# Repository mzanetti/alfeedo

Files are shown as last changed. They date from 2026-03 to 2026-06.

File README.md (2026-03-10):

# Alfeedo

A fully featured, smart home integrated cat feeder. 

This repository contains the firmware for the 3D printed cat feeder Alfeedo.

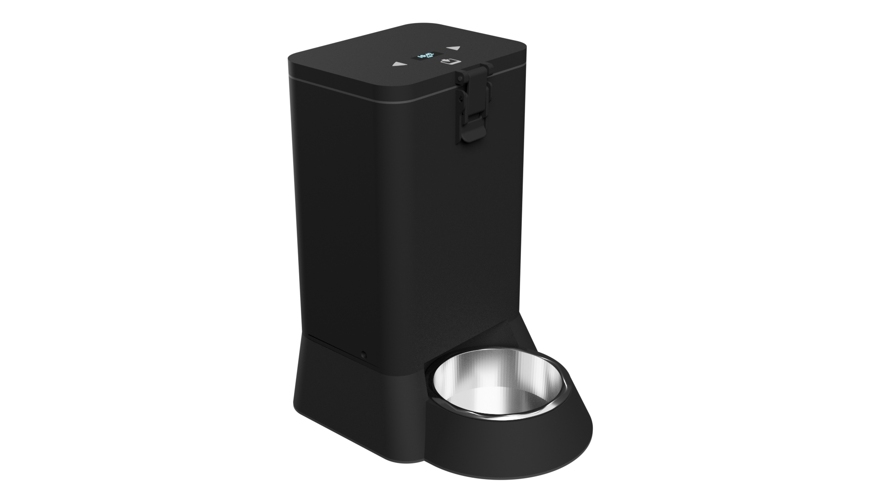
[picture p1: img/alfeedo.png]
Alfeedo


## Features

* Controls a TMC2209 stepper motor to dispense food (including jam detection and recovery)
* Supports operation and setup using a 128x32 display and Buttons
* Built-in web interface
* REST API

| Main view | Timer settings | Logs | Settings |
| :--- | :--- | :--- | :--- |
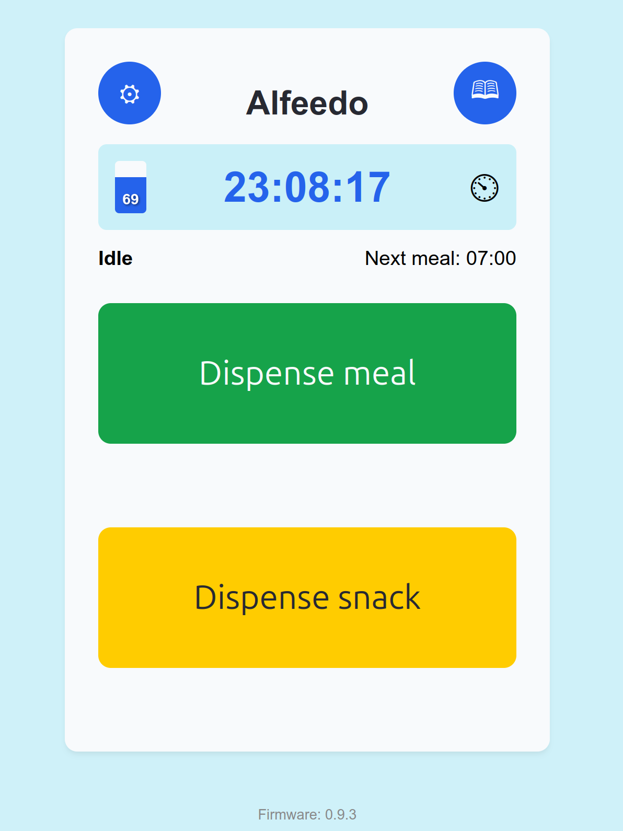
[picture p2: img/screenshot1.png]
Main
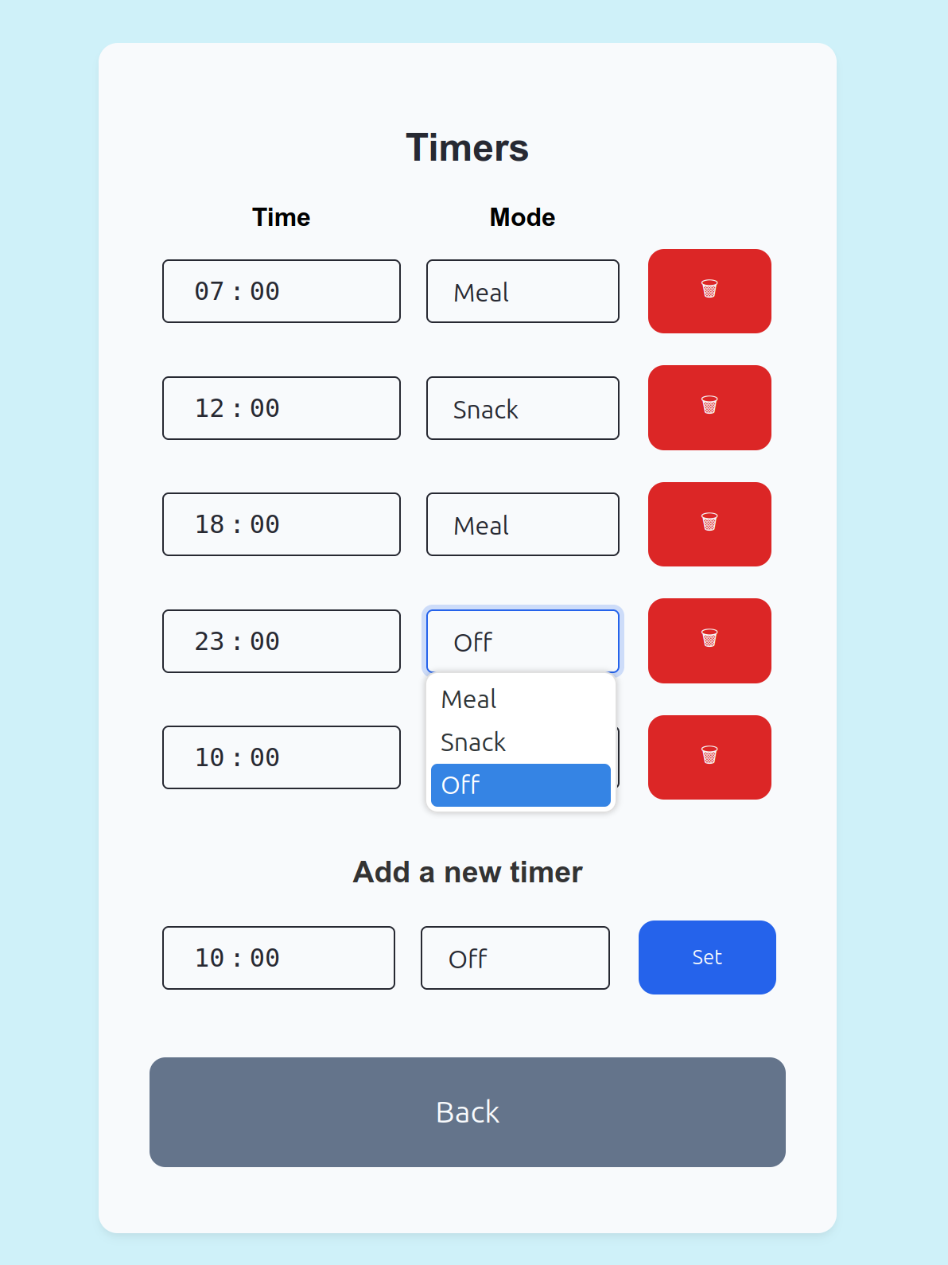
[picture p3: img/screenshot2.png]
Timers
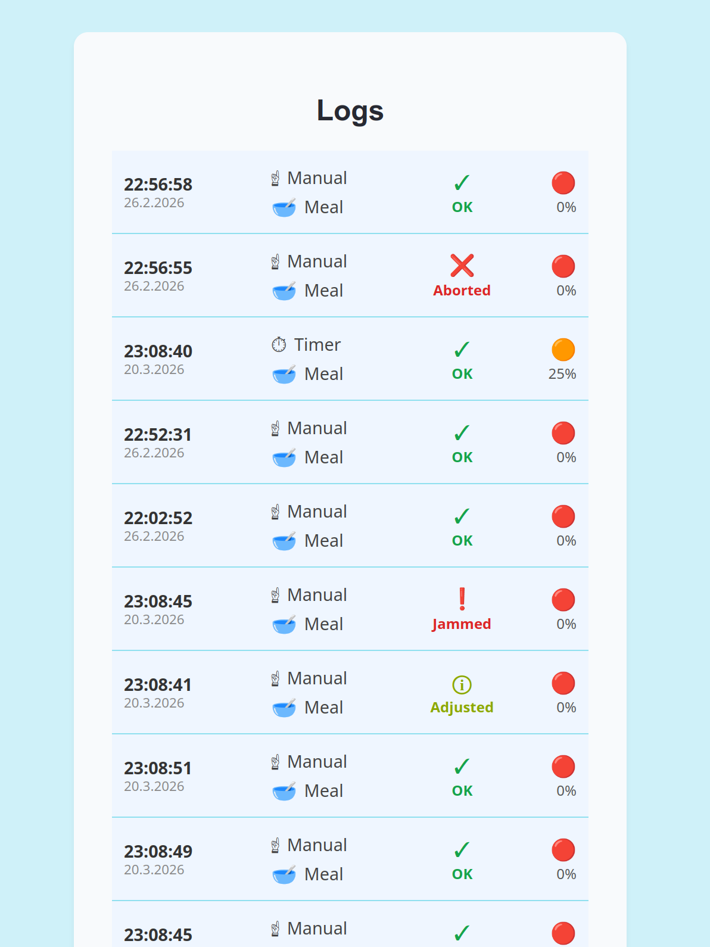
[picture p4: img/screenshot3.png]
Logs
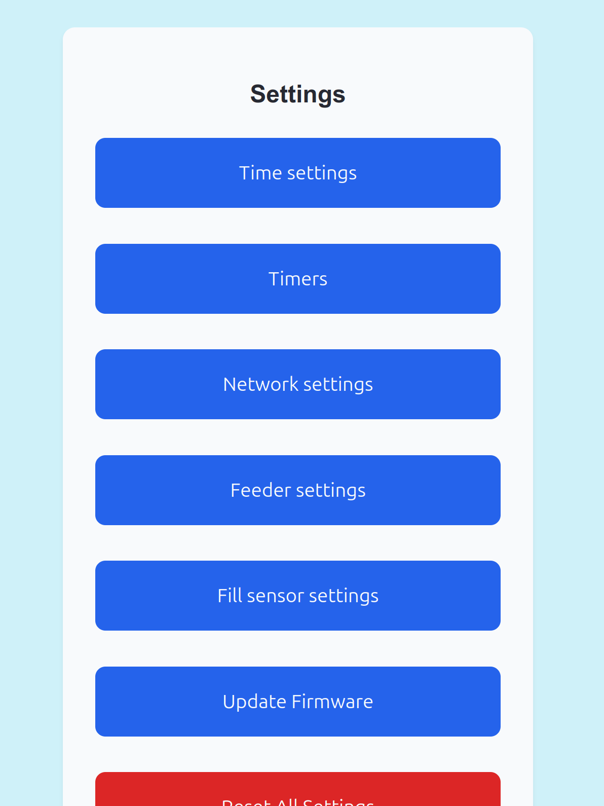
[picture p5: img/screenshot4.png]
Settings
|  |  |  |  |

## How to build

3D print model files along with a bill of materials are available on Makerworld. 

[Makerworld - Alfeedo](https://makerworld.com/en/models/2506745-alfeedo-smart-cat-feeder)

Follow print and assembly instructions provided with the model files.

Electronics wiring can be simplified by ordering the Alfeedo PCB using the provided Gerber files in [pcb/](https://github.com/mzanetti/alfeedo/tree/main/pcb).

Flash the device using the [web flasher](https://mzanetti.github.io/alfeedo/main/flasher/).

Note that the provided firmware assumes wiring to look like on the Alfeedo PCB. If instead you prefer using a different setup, you'll have to build the firmware yourself and adjust the pins in hwsettings.h.

## Building

This project is based on [platformio](https://platformio.org/).

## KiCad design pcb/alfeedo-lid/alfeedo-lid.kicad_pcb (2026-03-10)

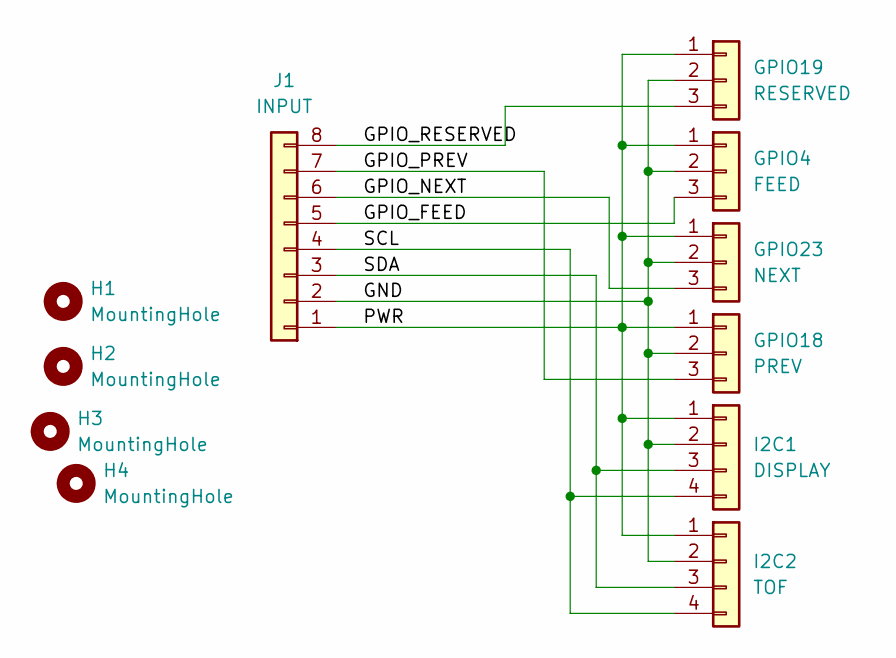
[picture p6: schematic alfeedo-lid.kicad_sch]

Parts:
GPIO4: FEED; JST_PH_S3B-PH-K_1x03_P2.00mm_Horizontal
GPIO18: PREV; JST_PH_S3B-PH-K_1x03_P2.00mm_Horizontal
GPIO19: RESERVED; JST_PH_S3B-PH-K_1x03_P2.00mm_Horizontal
GPIO23: NEXT; JST_PH_S3B-PH-K_1x03_P2.00mm_Horizontal
H1, H2, H3, H4: MountingHole; MountingHole_2.2mm_M2
I2C1: DISPLAY; JST_PH_S4B-PH-K_1x04_P2.00mm_Horizontal
I2C2: TOF; JST_PH_S4B-PH-K_1x04_P2.00mm_Horizontal
J1: INPUT; JST_PH_S8B-PH-K_1x08_P2.00mm_Horizontal

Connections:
/GND: GPIO4.2, GPIO18.2, GPIO19.2, GPIO23.2, I2C1.2, I2C2.2, J1.2
/GPIO_FEED: GPIO4.3, J1.5
/GPIO_NEXT: GPIO23.3, J1.6
/GPIO_PREV: GPIO18.3, J1.7
/GPIO_RESERVED: GPIO19.3, J1.8
/PWR: GPIO4.1, GPIO18.1, GPIO19.1, GPIO23.1, I2C1.1, I2C2.1, J1.1
/SCL: I2C1.4, I2C2.4, J1.4
/SDA: I2C1.3, I2C2.3, J1.3

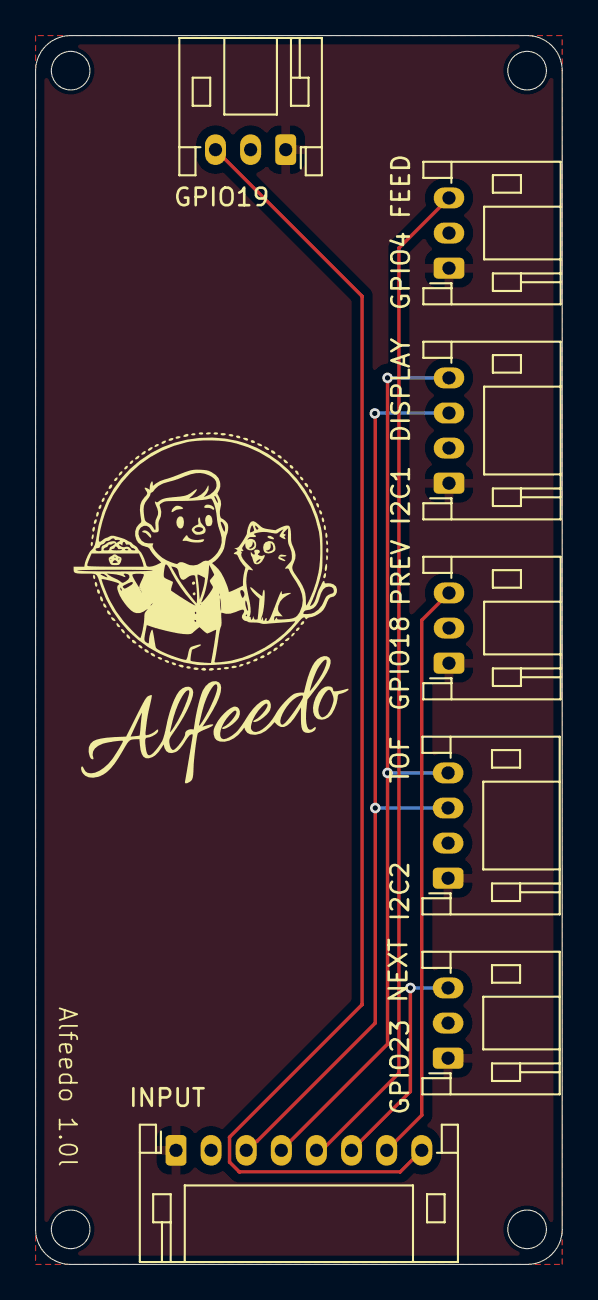
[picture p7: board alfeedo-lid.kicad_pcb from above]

Board: 2 copper layers, 30.0 x 70.0 mm, 11 parts (0 on the bottom side), 8 nets.

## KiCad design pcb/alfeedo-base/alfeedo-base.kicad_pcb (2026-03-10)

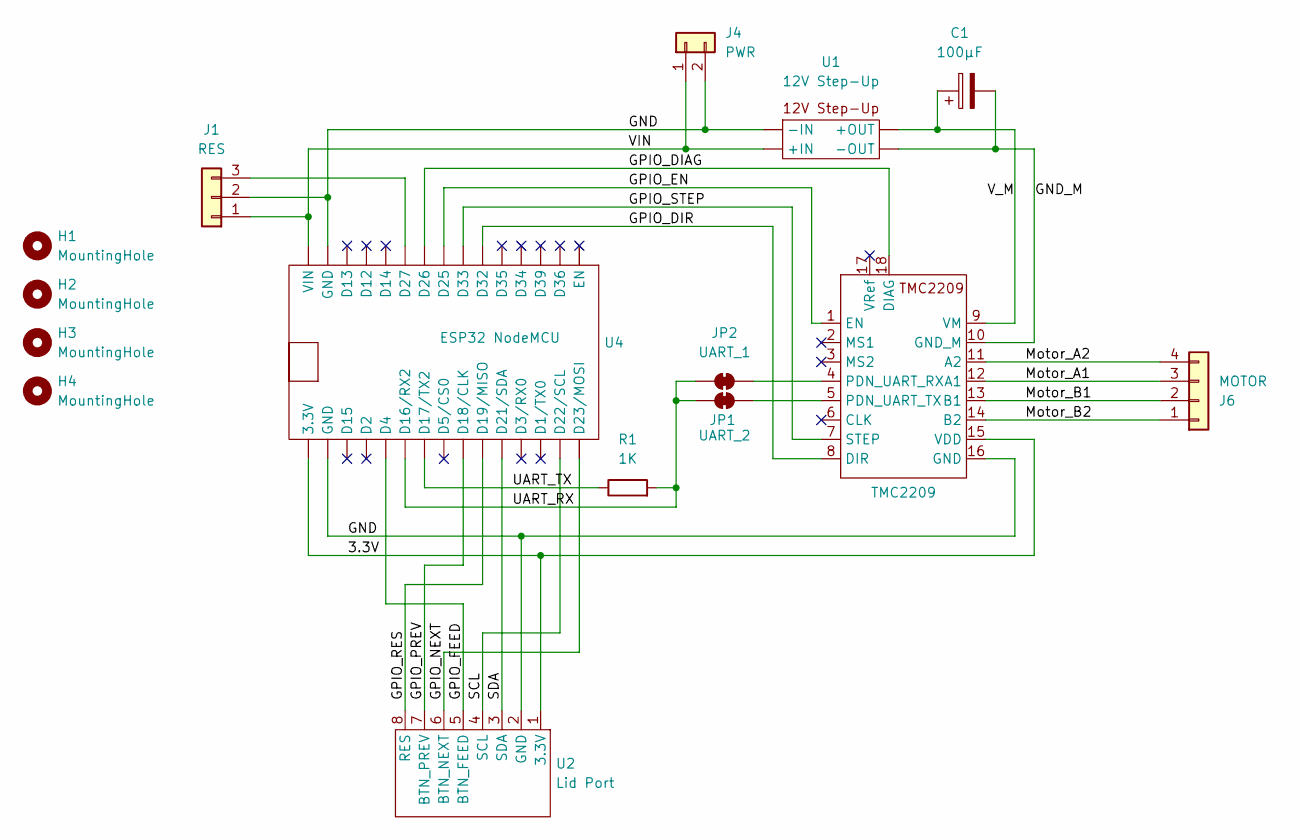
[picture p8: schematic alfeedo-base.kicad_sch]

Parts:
C1: 100µF; CP_Radial_D8.0mm_P2.50mm
H1, H2, H3, H4: MountingHole; MountingHole_2.2mm_M2
J1: RES; JST_XH_B3B-XH-A_1x03_P2.50mm_Vertical
J4: PWR; JST_XH_B2B-XH-A_1x02_P2.50mm_Vertical
J6: MOTOR; JST_XH_B4B-XH-A_1x04_P2.50mm_Vertical
JP1: UART_2; SolderJumper-2_P1.3mm_Bridged_RoundedPad1.0x1.5mm
JP2: UART_1; SolderJumper-2_P1.3mm_Bridged_RoundedPad1.0x1.5mm
R1: 1K; R_Axial_DIN0207_L6.3mm_D2.5mm_P7.62mm_Horizontal
TMC2209: TMC2209
U1: 12V Step-Up; 12V Step-up
U2: Lid Port; IDC-Header_2x04_P2.54mm_Vertical
U4: ESP32 NodeMCU; NodeMCU CH340

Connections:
/3.3V: TMC2209.15 (VDD), U2.1 (3.3V), U4.30 (3.3V)
/GND: J1.2, J4.2, TMC2209.16 (GND), U1.1 (-IN), U2.2 (GND), U4.14 (GND), U4.29 (GND)
/GND_M: C1.2, TMC2209.10 (GND_M), U1.3 (-OUT)
/GPIO_DIAG: TMC2209.18 (DIAG), U4.9 (D26)
/GPIO_DIR: TMC2209.8 (DIR), U4.6 (D32)
/GPIO_EN: TMC2209.1 (EN), U4.8 (D25)
/GPIO_FEED: U2.5 (BTN_FEED), U4.26 (D4)
/GPIO_NEXT: U2.6 (BTN_NEXT), U4.16 (D23/MOSI)
/GPIO_PREV: U2.7 (BTN_PREV), U4.22 (D18/CLK)
/GPIO_RES: U2.8 (RES), U4.21 (D19/MISO)
/GPIO_STEP: TMC2209.7 (STEP), U4.7 (D33)
/Motor_A1: J6.3, TMC2209.12 (A1)
/Motor_A2: J6.4, TMC2209.11 (A2)
/Motor_B1: J6.2, TMC2209.13 (B1)
/Motor_B2: J6.1, TMC2209.14 (B2)
/SCL: U2.4 (SCL), U4.17 (D22/SCL)
/SDA: U2.3 (SDA), U4.20 (D21/SDA)
/UART_RX: JP1.1 (A), JP2.1 (A), R1.2, U4.25 (D16/RX2)
/UART_TX: R1.1, U4.24 (D17/TX2)
/VIN: J1.1, J4.1, U1.2 (+IN), U4.15 (VIN)
/V_M: C1.1, TMC2209.9 (VM), U1.4 (+OUT)
unnamed: J1.3, U4.10 (D27)
unnamed: JP1.2 (B), TMC2209.5 (PDN_UART_TX)
unnamed: JP2.2 (B), TMC2209.4 (PDN_UART_RX)

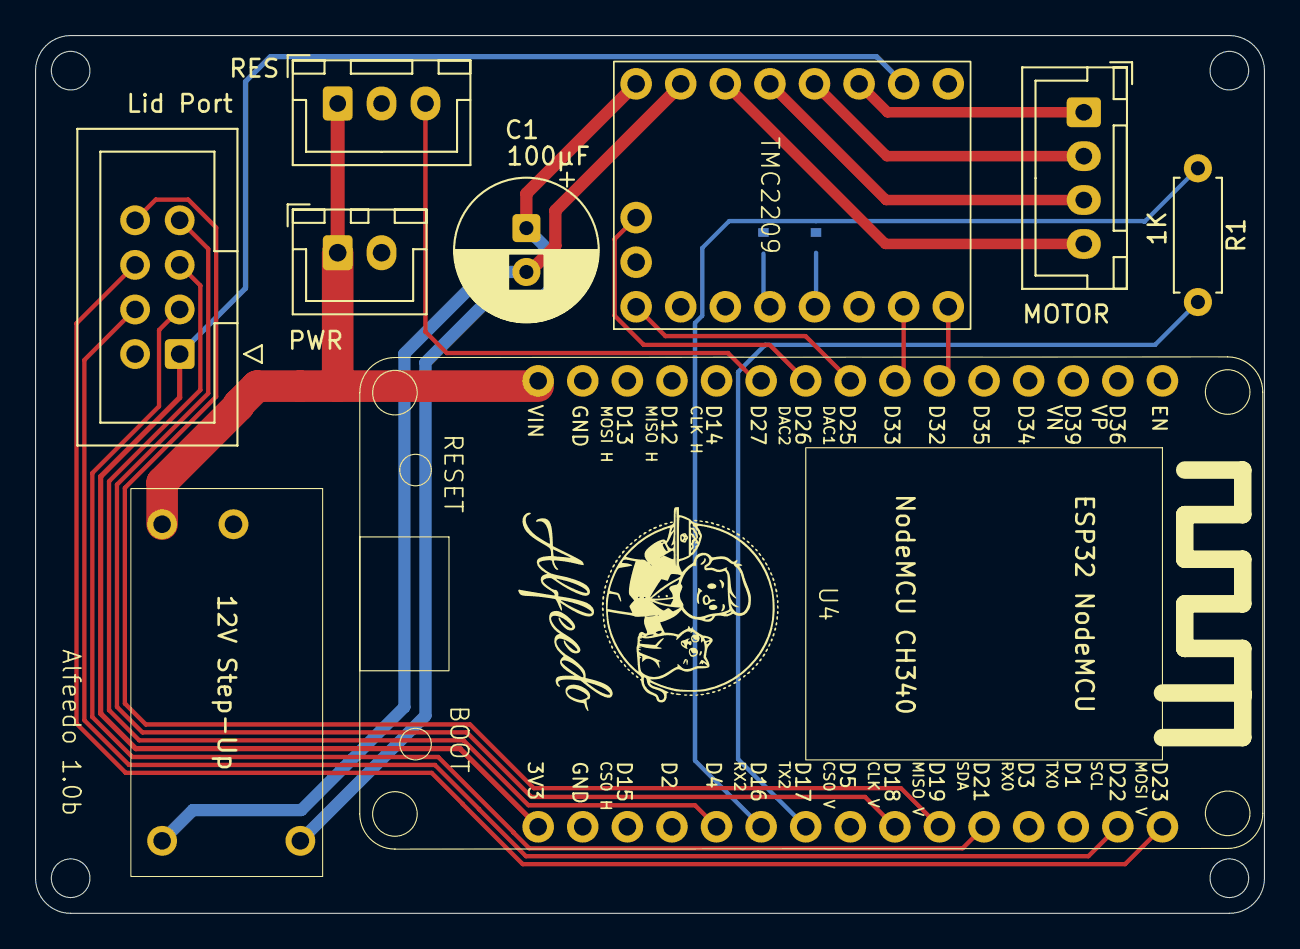
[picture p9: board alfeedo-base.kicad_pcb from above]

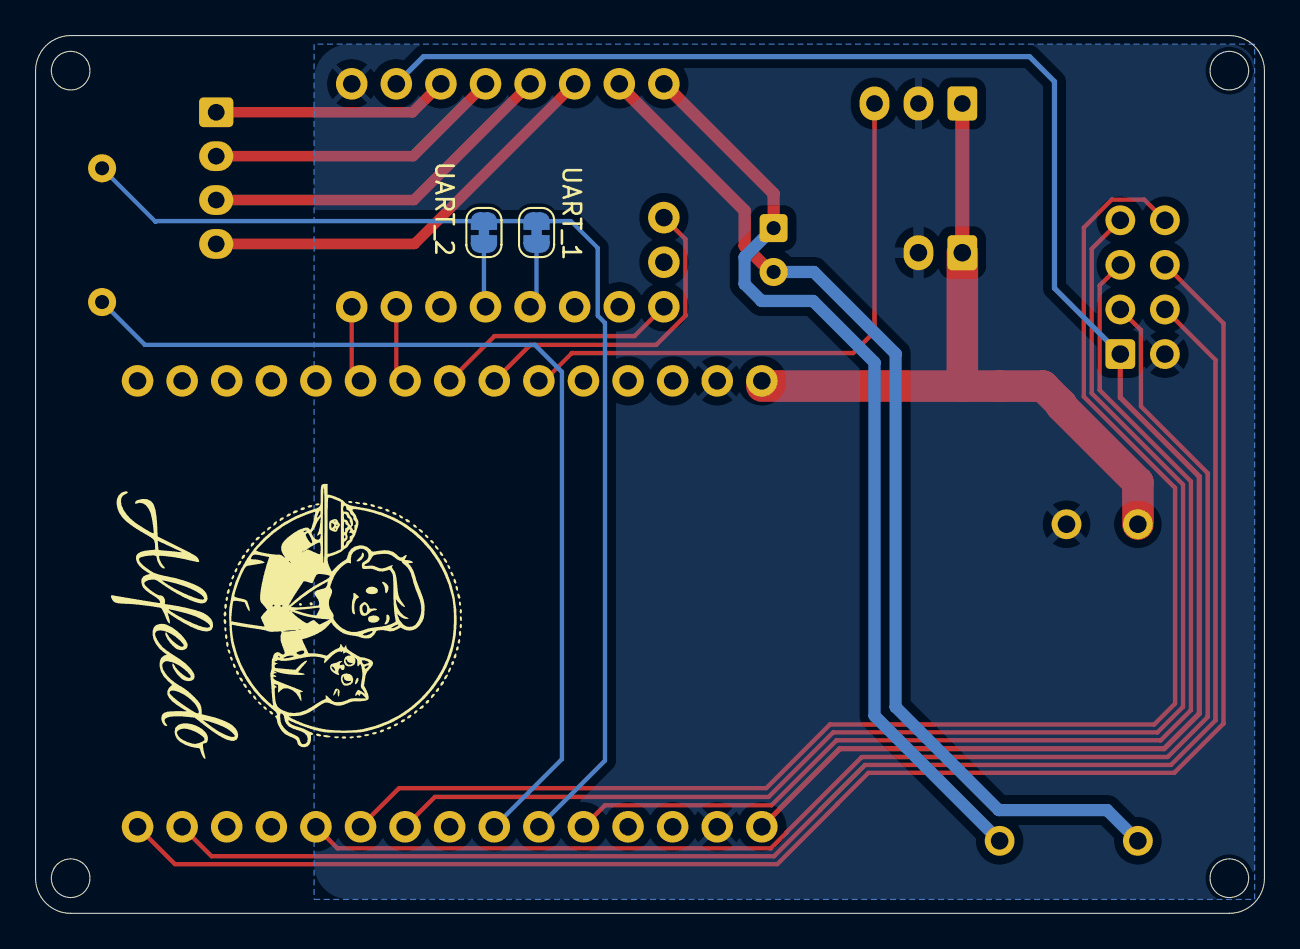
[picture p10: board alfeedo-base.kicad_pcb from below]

Board: 2 copper layers, 70.0 x 50.0 mm, 15 parts (2 on the bottom side), 24 nets.

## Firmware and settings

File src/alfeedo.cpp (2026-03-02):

/*
This file is part of alfeedo.

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
alfeedo is distributed in the hope that it will be useful, but WITHOUT ANY WARRANTY; 
without even the implied warranty of MERCHANTABILITY or FITNESS FOR A PARTICULAR PURPOSE.
See the GNU General Public License for more details.

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
Copyright (C) 2025-2026 Michael Zanetti <michael_zanetti@gmx.net>
*/

#include "webserver/CatServer.h"
#include "DisplayController.h"
#include "Engine.h"
#include "FillSensor.h"
#include "Motor.h"
#include "OTAManager.h"
#include "TimeSource.h"
#include "NetworkConfigManager.h"
#include "hwsettings.h"
#include "Logging.h"

#include <Arduino.h>
#include <SPIFFS.h>

#define DISPLAY_I2C_ADDR 0x3C
#define DISPLAY_WIDTH 128
#define DISPLAY_HEIGHT 32

LoggingCategory lcMain("Main");

Engine engine;
CatServer catserver;
Motor motor(DRIVER_STEP_PIN, DRIVER_DIRECTION_PIN, DRIVER_ENABLE_PIN, Serial2, UART_RX_PIN, UART_TX_PIN, DRIVER_DIAG_PIN);
OTAManager otaManager;
DisplayController displayController(DISPLAY_I2C_ADDR, DISPLAY_WIDTH, DISPLAY_HEIGHT);
FillSensor fillSensor;
TimeSource timeSource;
NetworkConfigManager networkConfigManager;

namespace ResetHandler {
    void resetAll() {
        logInfo(lcMain, "Performing factory reset...");
        engine.reset();
        displayController.reset();
        fillSensor.reset();
        timeSource.reset();
        networkConfigManager.reset();
    }
}

void setup() {
    Serial.begin(115200);
    delay(1000);
    logInfo(lcMain, "Meeeow!");

    if (!SPIFFS.begin(true)) {
        logError(lcMain, "Unable to mount SPIFFS");
        return;
    }

    timeSource.begin();
    
    networkConfigManager.begin();

    fillSensor.begin();
    
    engine.begin(&timeSource, &motor, &fillSensor);
    
    displayController.setup(&engine, &fillSensor, &otaManager, &timeSource, ResetHandler::resetAll, FEED_BUTTON_PIN, NEXT_BUTTON_PIN, PREVIOUS_BUTTON_PIN);

    catserver.begin(&engine, &fillSensor, &otaManager, &timeSource, &displayController, &networkConfigManager, ResetHandler::resetAll);
}

void loop() {
    timeSource.loop();
    engine.update();
    motor.loop();
    displayController.loop();
    fillSensor.loop();
    catserver.loop();
    networkConfigManager.loop();
}

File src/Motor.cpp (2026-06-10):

/*
This file is part of alfeedo.

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
alfeedo is distributed in the hope that it will be useful, but WITHOUT ANY WARRANTY; 
without even the implied warranty of MERCHANTABILITY or FITNESS FOR A PARTICULAR PURPOSE.
See the GNU General Public License for more details.

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
Copyright (C) 2025-2026 Michael Zanetti <michael_zanetti@gmx.net>
*/

#include "Motor.h"
#include "Logging.h"
#include "hwsettings.h"

LoggingCategory lcMotor("Motor");

HardwareSerial &TMC_SERIAL = Serial2;

Motor::Motor(int stepPin, int dirPin, int enablePin, HardwareSerial &serialPort, int uartRxPin, int uartTxPin, int diagPin):
    m_driver(&serialPort, R_SENSE, DRIVER_ADDRESS),
    m_serialPort(serialPort),
    m_stepPin(stepPin),
    m_directionPin(dirPin),
    m_enablePin(enablePin),
    m_uartRxPin(uartRxPin),
    m_uartTxPin(uartTxPin),
    m_diagPin(diagPin)
{
}

Motor::~Motor()
{
}

void IRAM_ATTR stallGuardInterrupt(void *arg)
{
    StallGuardISRContext *context = (StallGuardISRContext*)arg;

    int32_t currentPos = context->stepper->getCurrentPosition();
    context->stepper->forceStopAndNewPosition(currentPos);

    BaseType_t xHigherPriorityTaskWoken = pdFALSE;
    xSemaphoreGiveFromISR(context->stallFlag, &xHigherPriorityTaskWoken);
    if (xHigherPriorityTaskWoken == pdTRUE) {
        portYIELD_FROM_ISR();
    }

    // Printing from ISR is generally not recommended, may cause watchdog resets if the ISR is triggered too often.
    // Serial.println("*** STALLGUARD at position: " + String(currentPos) + " ***");
}

void Motor::begin() {

    pinMode(m_enablePin, OUTPUT);
    pinMode(m_directionPin, OUTPUT);
    pinMode(m_stepPin, OUTPUT);

    m_engine.init();
    m_stepper = m_engine.stepperConnectToPin(m_stepPin);
    m_stepper->setDirectionPin(m_directionPin);
    m_stepper->setEnablePin(m_enablePin);
    m_stepper->setCurrentPosition(0);
    m_stepper->setAutoEnable(true);
    m_stepper->setAcceleration(10000);

    m_stallGuardContext.stallFlag = xSemaphoreCreateBinary();
    m_stallGuardContext.stepper = m_stepper;

    pinMode(m_diagPin, INPUT_PULLDOWN);
    if (digitalPinCanOutput(m_diagPin) < 0) {
        logError(lcMotor, "Stallguard pin not usable as interrupt pin");
    }
    attachInterruptArg(m_diagPin, stallGuardInterrupt, &m_stallGuardContext, RISING);

    m_serialPort.begin(115200, SERIAL_8N1, m_uartRxPin, m_uartTxPin);
    
    m_driver.begin();
    
    logInfo(lcMotor, "Connection to TMC2209: " + String(m_driver.test_connection() == 0 ? "Working" : "not working"));
    logDebug(lcMotor, "TMC2209 version: " + String(m_driver.version()));
    logDebug(lcMotor, "TMC2209 initial DRV_STATUS: " + String(m_driver.DRV_STATUS(), BIN));

    // There are a lot of incomplete resources on the TMC2209 out there
    // Most useful: https://gist.github.com/metalinspired/dcfe07ed0b9f42870eb54dcf8e29c126
    // Datasheet: https://www.analog.com/media/en/technical-documentation/data-sheets/TMC2209_datasheet_rev1.08.pdf

    m_driver.toff(4);
    m_driver.blank_time(32);
    m_driver.microsteps(MOTOR_MICROSTEPS);
    m_driver.stealth();
    m_driver.rms_current(MOTOR_RMS_CURRENT);
    m_driver.SGTHRS(5); // Stallguard threshold (sensitivity) Works fine with Bigtreetech v1.3
    // Minimum speed for stallguard to be enabled (0xFFFFF = enabled at all speeds)
    // When accellerating/decellerating it gets unreliable, so tuning it down
    m_driver.TCOOLTHRS(0x00300);  // Works fine with Bigtreetech 1.3
    
    
    logInfo(lcMotor, "TMC2209 configred. MS: " + String(m_driver.microsteps())
    + ", RMS Current: " + String(m_driver.rms_current()) + "mA"
    + ", SGTHRS: " + String(m_driver.SGTHRS())
    + ", TCOOLTHRS: " + String(m_driver.TCOOLTHRS())
    + ", TSTEP: " + String(m_driver.TSTEP())
    + ", GCONF: " + String(m_driver.GCONF(), BIN)
    );
    logDebug(lcMotor, "TMC2209 DRV_STATUS: " + String(m_driver.DRV_STATUS(), BIN));

}
 
void Motor::move(float revolutions)
{
    int steps = revolutions * MOTOR_STEPS_PER_REVOLUTION * GEAR_RATIO * (MOTOR_MICROSTEPS > 0 ? MOTOR_MICROSTEPS : 1);
    m_targetPosition = m_stepper->getCurrentPosition() + steps;
    m_stepper->moveTo(m_targetPosition);
    m_state = State::Moving;

    logInfo(lcMotor, "Moving motor " + String(revolutions) + " revs (" + String(steps) + " steps) to target " + String(m_targetPosition));
}   

void Motor::setSpeed(float speed)
{
    int microsteps = MOTOR_MICROSTEPS > 0 ? MOTOR_MICROSTEPS : 1;
    float stepsPerSec = speed * MOTOR_STEPS_PER_REVOLUTION * microsteps;
    logInfo(lcMotor, "Setting motor speed to " + String(speed) + " revolutions/sec (Steps/second: " + String(stepsPerSec) + ")");

    m_stepper->setSpeedInHz(speed * MOTOR_STEPS_PER_REVOLUTION * MOTOR_MICROSTEPS * GEAR_RATIO);
}

float Motor::getSpeed() const
{
    return 1.0 * const_cast<FastAccelStepper *>(m_stepper)->getSpeedInMilliHz() / 1000 / MOTOR_STEPS_PER_REVOLUTION / MOTOR_MICROSTEPS / GEAR_RATIO; 
}

void Motor::loop()
{
#if DEBUG_STALLGUARD
    static long last = 0;
    long now = millis();
    if (now - last > 500 && m_state != State::Idle) {
        last = now;
        int value = m_driver.SG_RESULT();
        // int tstep = m_driver.TSTEP();
        Serial.println("MOTOR_DBG: SG_RESULT: " + String(value));// + ", TSTEP: " + String(tstep));
    }
#endif

    if (xSemaphoreTake(m_stallGuardContext.stallFlag, 0) == pdTRUE && m_state == State::Moving) {
        logInfo(lcMotor, "Stall detected via StallGuard!");
        m_state = State::Stalled;
    }

    switch (m_state) {
    case State::Idle:
        break;
    case State::Moving:
        if (!m_stepper->isRunning()) {
            if (m_stepper->getCurrentPosition() == m_targetPosition){
                logInfo(lcMotor, "Target destination reached: " + String(m_stepper->getCurrentPosition()));
                m_stepper->setCurrentPosition(0);
                m_state = State::Idle;
            } else {
                logWarning(lcMotor, "Movement ended prematurely at position: " + String(m_stepper->getCurrentPosition()) + ", expected: " + String(m_targetPosition));
                m_state = State::Stalled;
            }
        }
        break;
    case State::Stalled: {
        logInfo(lcMotor, "Starting stallguard recovery routine (moving back 100 steps).");
        int32_t currentPos = m_stepper->getCurrentPosition();
        // m_stepper->forceStopAndNewPosition(currentPos);
        m_stepper->moveTo(currentPos-2000);
        m_state = State::Reverse;
        m_stallCount++;
        break;
        }
    case State::Reverse:
        if (!m_stepper->isRunning()) {
            logInfo(lcMotor, "Resuming to target position: " + String(m_targetPosition));

            m_stepper->moveTo(m_targetPosition);
            m_state = State::Moving;
        }
        break;
    }
}

bool Motor::isMoving() const
{
    return m_state != State::Idle;
}

int Motor::stallCount() const {
    return m_stallCount;
}

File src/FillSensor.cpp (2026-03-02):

/*
This file is part of alfeedo.

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
alfeedo is distributed in the hope that it will be useful, but WITHOUT ANY WARRANTY; 
without even the implied warranty of MERCHANTABILITY or FITNESS FOR A PARTICULAR PURPOSE.
See the GNU General Public License for more details.

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
Copyright (C) 2025-2026 Michael Zanetti <michael_zanetti@gmx.net>
*/

#include "FillSensor.h"
#include "Logging.h"

#include <numeric>

LoggingCategory lcFillSensor("FillSensor");

constexpr const char *PREFS_NAME = "fillSensor";
constexpr int defaultFullMeasurement = 20;
constexpr int defaultEmptyMeasurement = 100;

constexpr int maxHistory = 20;

void FillSensor::begin()
{
    logInfo(lcFillSensor, "Initializing VL53L0X sensor...");

    if (!Wire.begin()) {
        logError(lcFillSensor, "I2C initialization failed");
        return;
    }

    Wire.beginTransmission(VL53L0X_I2C_ADDR);
    if (Wire.endTransmission() != 0) {
        logError(lcFillSensor, "VL53L0X not found on I2C bus");
        return;
    }

    if (!m_lox.begin()) {
        logError(lcFillSensor, "Failed to boot VL53L0X");
        return;
    }
    m_initialized = true;
    logInfo(lcFillSensor, "VL53L0X started");

    m_prefs.begin(PREFS_NAME);
    m_emptyMeasurement = m_prefs.getInt("empty", defaultEmptyMeasurement);
    m_fullMeasurement = m_prefs.getInt("full", defaultFullMeasurement);
    m_prefs.end();

    logInfo(lcFillSensor, "Settings loaded. Full: " + String(m_fullMeasurement) + ", Empty: " + String(m_emptyMeasurement));
}

void FillSensor::loop()
{
    if (!m_initialized) {
        return;
    }

    
    if (millis() - m_lastReading < 1000) {
        return;
    }
    m_lastReading = millis();

    VL53L0X_RangingMeasurementData_t measure;
    VL53L0X_Error status = m_lox.rangingTest(&measure, false);

    if (status != VL53L0X_ERROR_NONE) {
        logError(lcFillSensor, "Error during ranging");
        return;
    }

    if (measure.RangeStatus == 4) {  // phase failures have incorrect data
        logWarning(lcFillSensor, "Measurement out of range");
        return;
    }

    m_rawMeasurement = measure.RangeMilliMeter;

    if (abs(m_rawMeasurement - m_measurement) > 10) {
        logDebug(lcFillSensor, "Resetting fill sensor filter.");
        m_history.clear();
    }

    m_history.push_back(m_rawMeasurement);
    if (m_history.size() > maxHistory) {
        m_history.erase(m_history.begin(), m_history.begin() + m_history.size() - 10);
    }
    m_measurement = round(std::accumulate(m_history.begin(), m_history.end(), 0) / m_history.size());
    
    // // Linear (for a square container)
    // m_fillLevel = map(measure.RangeMilliMeter, m_emptyMeasurement, m_fullMeasurement, 0, 100);
    // m_fillLevel = constrain(m_fillLevel, 0, 100);
    

    // proportional (for a rectangular funnel)
    const float height = m_emptyMeasurement - m_fullMeasurement;
    const float lengthTop = 150;
    const float widthTop = 100;
    const float lengthBottom = 45;
    const float widthBottom = 35;
    const float areaTop = lengthTop * widthTop;
    const float areaBottom = lengthBottom * widthBottom;
    
    const float volumeTotal = (height / 3.0) * (areaTop + areaBottom + sqrt(areaTop * areaBottom));
    
    const float heightFood = max(m_emptyMeasurement - m_measurement, 0);
    const float lengthFood = lengthBottom + (heightFood / height) * (lengthTop - lengthBottom);
    const float widthFood = widthBottom + (heightFood / height) * (widthTop - widthBottom);
    const float areaFood = lengthFood * widthFood;
    
    const float volumeFood = (heightFood / 3.0) * (areaFood + areaBottom + sqrt(areaFood * areaBottom));
    
    m_fillLevel = volumeFood / volumeTotal * 100.0;
    m_fillLevel = constrain(m_fillLevel, 0, 100);
    
#if DEBUG_FILLSENSOR
    logDebug(lcFillSensor, "Distance (mm): " + String(m_measurement) + " (raw: " + String(m_rawMeasurement) + ")" 
        + ", FillLevel: " + String(m_fillLevel) 
        + ", Vol. food: " + String(volumeFood)
        + ", Vol total: " + String(volumeTotal)
        + ", Height total: " + String(height) + " food: " + String(heightFood));
#endif
}

bool FillSensor::initialized() const {
    return m_initialized;
}

int FillSensor::fillLevel() const
{
    return m_fillLevel;
}

int FillSensor::measurement() const
{
    return m_measurement;
}

int FillSensor::rawMeasurement() const {
    return m_rawMeasurement;
}

int FillSensor::emptyMeasurement() const
{
    return m_emptyMeasurement;
}

void FillSensor::setEmptyMeasurement(int emptyMeasurement)
{
    logInfo(lcFillSensor, "Empty measurement set to: " + String(emptyMeasurement));
    m_emptyMeasurement = emptyMeasurement;
    m_prefs.begin(PREFS_NAME);
    m_prefs.putInt("empty", m_emptyMeasurement);
    m_prefs.end();
}

int FillSensor::fullMeasurement() const
{
    return m_fullMeasurement;
}

void FillSensor::setFullMeasurement(int fullMeasurement)
{
    logInfo(lcFillSensor, "Full measurement set to: " + String(fullMeasurement));
    m_fullMeasurement = fullMeasurement;
    m_prefs.begin(PREFS_NAME);
    m_prefs.putInt("full", m_fullMeasurement);
    m_prefs.end();
}

void FillSensor::reset()
{
    logInfo(lcFillSensor, "Resetting settings...");
    m_fullMeasurement = defaultFullMeasurement;
    m_emptyMeasurement = defaultEmptyMeasurement;

    m_prefs.begin(PREFS_NAME);
    m_prefs.clear();
    m_prefs.end();
}

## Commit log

2026-03-10 Add the Alfeedo PCB project
    [alfeedo-base.kicad_pcb, alfeedo-base.kicad_sch, alfeedo-lid.kicad_pcb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]
2026-03-28 Pin newer pioarduino toolkit
2026-06-10 Add gear ratio setting

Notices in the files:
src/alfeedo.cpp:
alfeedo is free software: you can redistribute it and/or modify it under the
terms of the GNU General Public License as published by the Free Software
